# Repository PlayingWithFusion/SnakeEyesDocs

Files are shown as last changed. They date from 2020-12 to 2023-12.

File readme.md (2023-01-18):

# [SnakeEyes Raspberry Pi Hat](https://www.playingwithfusion.com/productview.php?pdid=133&catid=1014)

## What Is It?

SnakeEyes is a circuit board which conforms to the Raspberry Pi hat physical specifications, and provides the following functionality:

 * 12V Passive POE extraction (for supported Pi models)
 * High-power, software-dimmable LED target illumination
   * Two versions available: [**traditional green**](https://www.playingwithfusion.com/productview.php?catid=1014&pdid=133) and [**infrared**](https://www.playingwithfusion.com/productview.php?catid=1014&pdid=134).
 * Regulated power supply for LED's and Raspberry Pi main board
 * Connections for cooling fan

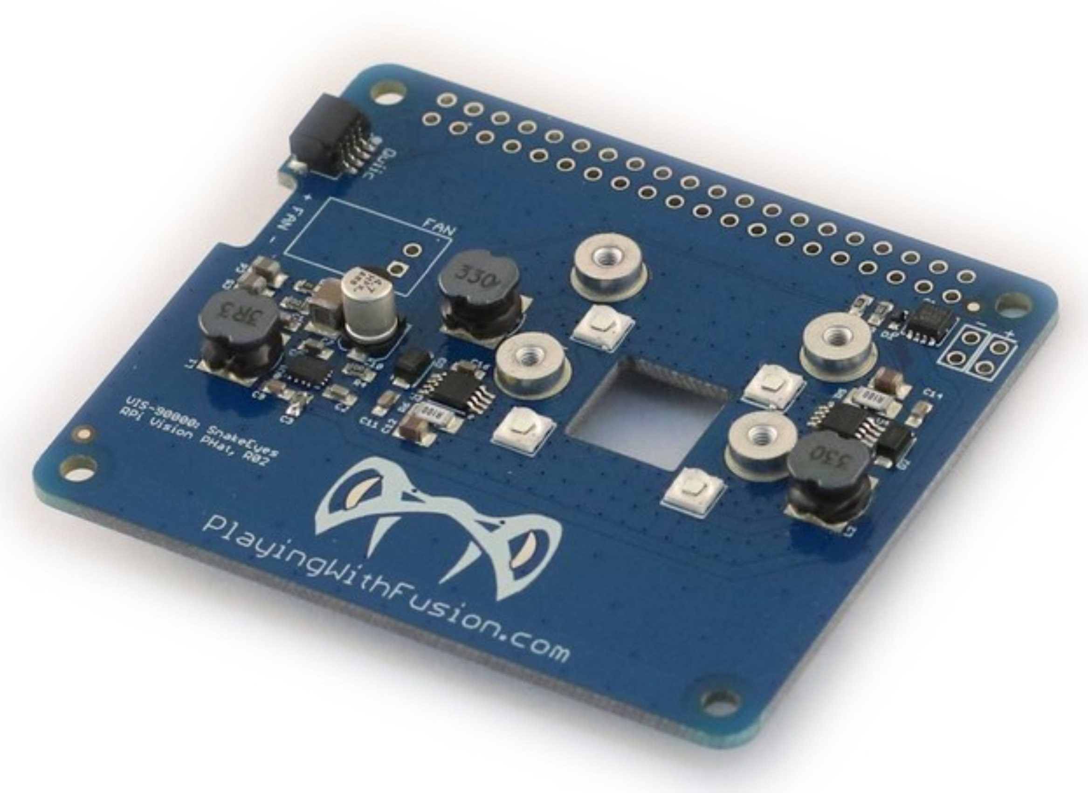
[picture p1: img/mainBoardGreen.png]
SnakeEyes main board photo


## What Is It Not?

SnakeEyes is designed to be one core component in a vision processing solution - it is not a plug-and-play vision processing solution by itself. The goal is to give teams flexibility to build and customize a system as they desire, while robustly taking care of "less-critical" electrical considerations.

SnakeEyes will require some assembly and fabrication, as well as some work to load and run software. 

## How to Use This Guide

This is a guide to help you get set up using the SnakeEyes vision processing hat. 

The platform is designed for experimentation! The goal is help DIY folks with a portion of their development process. 

This guide seeks to further help by providing a few known-good paths to success.

# Getting Started

 1. [Video Introduction to the Product](https://www.youtube.com/watch?v=mmTHJN22qKk&feature=youtu.be)
 2. [Required Additional Hardware](hardware.md)
 3. [Sample 3D Printed Case Designs](case/)
 4. [Sample Software Options](sampleSoftware.md)

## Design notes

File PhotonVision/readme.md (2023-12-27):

# PhotonVision and SnakeEyes

[PhotonVision](https://photonvision.org) is one option for vision processing software which is compatible with SnakeEyes.

# Getting Started

Download the latest [preconfigured SnakeEyes Image](https://github.com/PlayingWithFusion/SnakeEyesDocs/releases).

Flash it onto an SD card [using the same process as recommended by PhotonVision](https://docs.photonvision.org/en/latest/docs/getting-started/installation/sw_install/raspberry-pi.html)

The reset of the [PhotonVision docs](https://docs.photonvision.org/en/latest/index.html) should apply as normal.

# Technical Details

The only modification to PhotonVision required to use SnakeEyes is to ensure the [`hardwareConfig.json`](hardwareConfig.json) file is updated to enable dimmable LED support on pin 13.

In 2024, PhotonVision migrated to using an SQLite database to store settings. Its contents is functionally the same as the `hardwareConfig.json` file. The SnakeEyes preconfigured image includes a small database with the LED's configured, but no cameras or pipelines configured. On PhotonVision's first launch, it will fill out the rest of the details for your model of Pi and camera config.

# Legacy Update Process

While still functional for the 2024 season, this method may be removed in the future. 

First, download the hardware config file, `hardwareConfig.json`. [Click this link](https://raw.githubusercontent.com/PlayingWithFusion/SnakeEyesDocs/master/PhotonVision/hardwareConfig.json), then save the file.

[Follow the instructions for installing PhotonVision.](https://docs.photonvision.org/en/latest/docs/getting-started/installation/coprocessor-image.html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)

Go to `http://photonvision.local:5800/settings.html`, select Import Settings, and upload `hardwareConfig.json`.

Successful configuration should allow you to see and control the LED brightness from the PhotonVision Settings page:

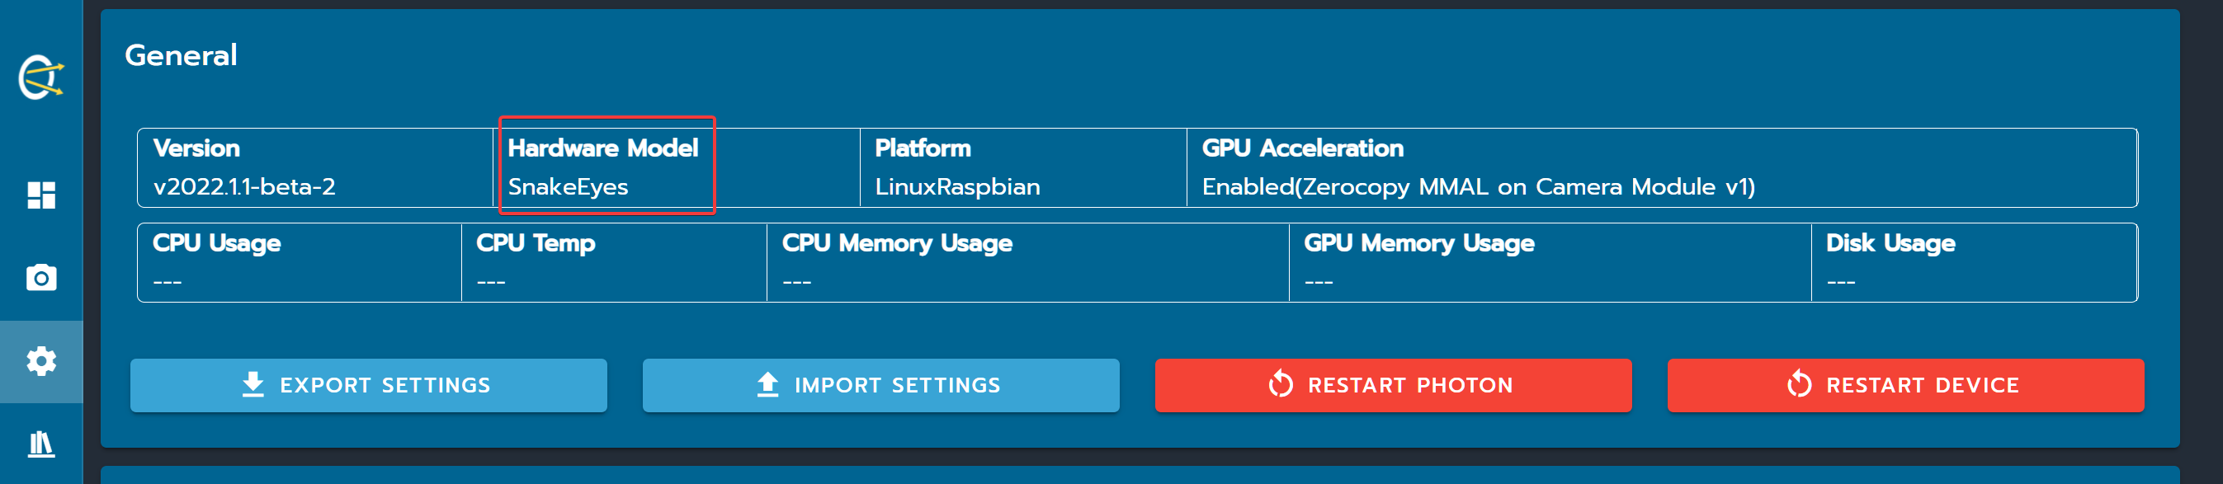
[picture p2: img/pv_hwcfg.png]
hardware config


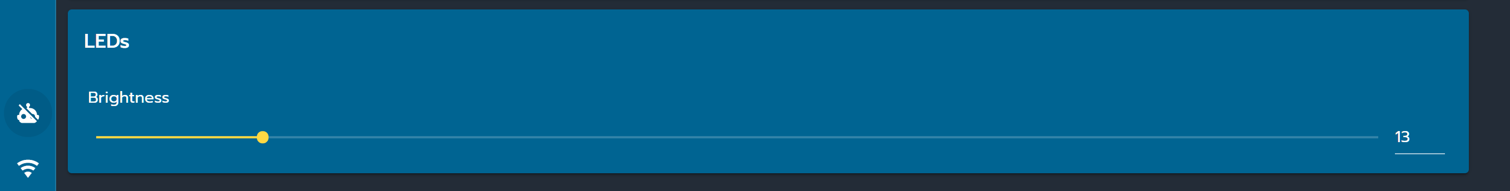
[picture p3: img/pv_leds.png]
LED slider


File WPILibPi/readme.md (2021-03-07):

# WPILibPi and SnakeEyes

This sample code runs on the WPIlib Raspberry Pi Image, and performs basic image processing on an IR camera, as well as interfaces with an LED & power supply hat from Playing With Fusion.

The sample code assumes the Raspberry Pi NOIR camera is in use, and no other cameras are attached to the system.

# Getting Started

This procedure was last tested with the v2021.2.1 release of WPILib Pi.

## Code

Download a copy of the sample [`snakeEyesVision.py`](https://raw.githubusercontent.com/PlayingWithFusion/SnakeEyesDocs/master/WPILibPi/snakeEyesVision.py) script. Modify the `TEAM_NUMBER` variable to match your team, along with other configuration as needed.

## Upload

[Download and flash the latest version of the FRCVision Raspberry Pi Image per their instructions.](https://docs.wpilib.org/en/stable/docs/software/vision-processing/raspberry-pi/installing-the-image-to-your-microsd-card.html)

Power the system up, visit the web interface, and ensure you can see the Raspberry Pi camera as the only camera on the system, and can view its stream.

[Reference the Vision Workflows documentation](https://docs.wpilib.org/en/stable/docs/software/vision-processing/raspberry-pi/the-raspberry-pi-frc-console.html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) to upload your modified `snakeEyesVision.py`.

> :bug: To debug, you can change to the `Vision Status` tab, and ensure you have messages indicating the vision processing logic has started.

> :bug: Note that the python example uses the `RPi.GPIO` libraries for controlling the pins as a simple proof of concept. However, since it only supports software PWM, you may see **occasional flickering** in the output intensity at partial values. In the future, we're looking to use `pigpio` as an alternative, but that requires more complex integration.

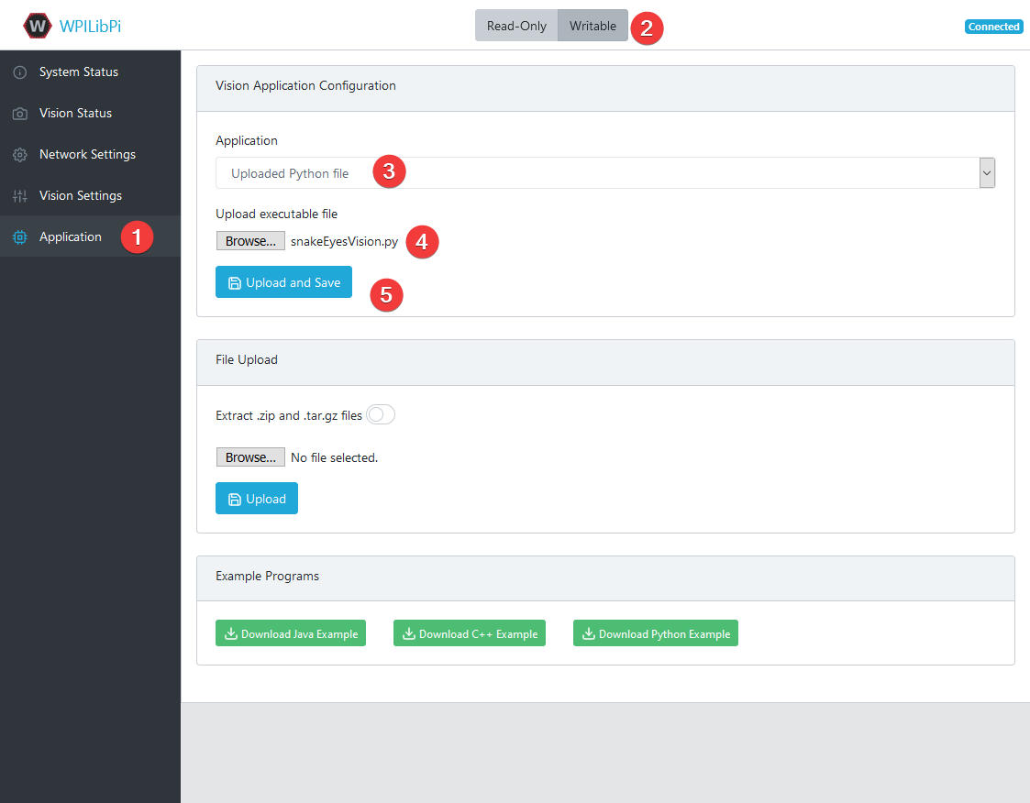
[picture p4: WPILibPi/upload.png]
upload sequence


Once the code is running, visit [`http://wpilibpi.local:5805/stream.html`](http://wpilibpi.local:5805/stream.html) in a web browser to see a stream of the processed camera data and some stats.

You can read the target information from Network Tables values `targetX`, `targetY`, and `targetVisible`.

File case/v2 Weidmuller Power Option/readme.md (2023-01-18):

# v2 Case with Weidmuller Power Access

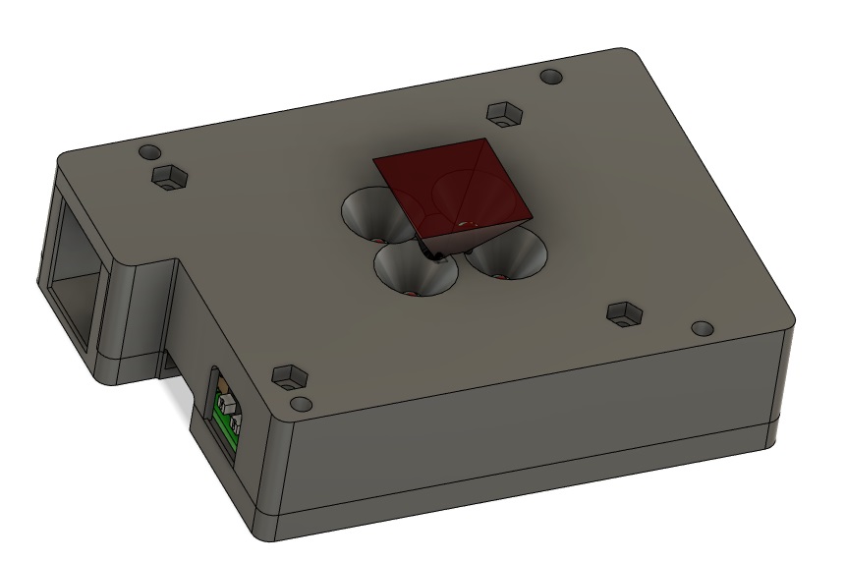
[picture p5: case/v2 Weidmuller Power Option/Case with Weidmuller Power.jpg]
v2 caseW eidmuller


This case improves the v1 design with fewer clearance issues, fewer small parts to manage, and increased sd card access. It also includes access port for the external Weidmuller power ports.

You will need all the same metric bolt hardware as the v1 case, and need to print one of each .stl.

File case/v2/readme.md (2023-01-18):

# v2 Case

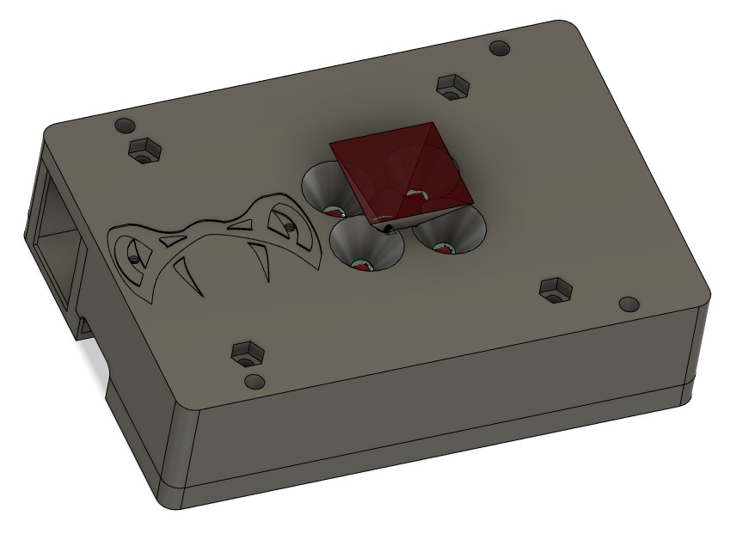
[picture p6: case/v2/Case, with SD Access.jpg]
v2 case


This case improves the v1 design with fewer clearance issues, fewer small parts to manage, and increased sd card access.

You will need all the same metric bolt hardware as the v1 case, and need to print one of each .stl.

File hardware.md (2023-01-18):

# Hardware

This page describes the minimum additional hardware required to enable all functionality of the SnakeEyes board.

> :warning: If you are using the [Sample Case Design](case/v1/sampleCase.md), be sure to read that page too - it has additional components and requirements above and beyond these minimum requirements.

## BOM

| No. | Description | Quantity | Example Source
| --- | --- | --- | --- |
| 1 | SnakeEyes Pi Hat | 1 | [Green](https://www.playingwithfusion.com/productview.php?catid=1014&pdid=133) or [IR](https://www.playingwithfusion.com/productview.php?pdid=134)
| 2 | Compatible Raspberry Pi | 1 | See below
| 3 | 20x2 0.1" pitch header | 1 | Included, or [Kit from Amazon.com](https://www.amazon.com/gp/product/B076H25ZB8)
| 4 | 2x2 0.1" pitch header | 1 | Included, or [Kit from Amazon.com](https://www.amazon.com/gp/product/B076H25ZB8)
| 5 | Pi V2 or V1.3 Camera | 1 | [Green](https://www.raspberrypi.org/products/camera-module-v2/?resellerType=home) or [IR](https://www.raspberrypi.org/products/pi-noir-camera-v2/?resellerType=home) 
| 6 | M2x10mm screws | 4 | [Set from Amazon.com](https://www.amazon.com/uxcell-M2x10mm-Phillips-Stainless-Fasteners/dp/B07LGWJ9LJ/)
| 7 | Short Camera Cable | 1 | [Set from Amazon.com](https://www.amazon.com/Pastall-Raspberry-15cm%C3%972pcs-30cm%C3%972pcs-50cm%C3%972pcs/dp/B089LM5D1T)
| 8 | 12v cooling fan | 1 | [Set from Amazon.com](https://www.amazon.com/gp/product/B01406OSNE)
| 9 | Case | 1 | [Sample Case Design](case/v1/sampleCase.md), one of the v2 designs, or create your own.

## Component Details

### Raspberry Pi

SnakeEyes is designed to fit the "hat" form-factor of the [Raspberry Pi Single Board computer](https://www.raspberrypi.org/products/). Specifically, the following variants have been tested:

 * [4 Model B](https://www.raspberrypi.org/products/raspberry-pi-4-model-b/?resellerType=home)
 * [3 Model B+](https://www.raspberrypi.org/products/raspberry-pi-3-model-b-plus/?resellerType=home)
 * [3 Model B](https://www.raspberrypi.org/products/raspberry-pi-3-model-b/?resellerType=home)

Others will likely function, but have not been fully tested. Earlier models had limited processing power, so your algorithm's performance may not be as good as with recent models.

### Headers & Soldering

SnakeEyes does not come assembled with the headers required to interface with a Raspberry Pi. 

Carefully solder all headers onto the SnakeEyes board. Use jigs as needed to ensure the headers are straight and flush with the PCB, as this alignment contributes to the overall camera alignment in the unit.

> :warning: Use particular caution soldering near the small 4-pin header - it is easy to damage nearby surface-mount components.

The 2x2 pin header is used for Power over Ethernet.

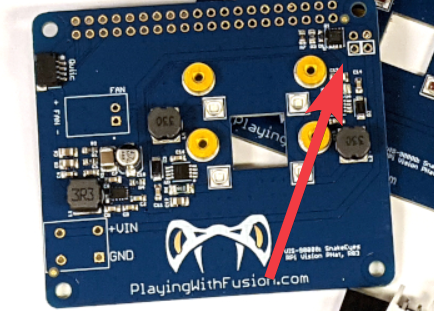
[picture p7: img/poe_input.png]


 If you are using a Raspberry Pi model which does not support power over ethernet (like the 3 Model B), or do not wish to use Power over Ethernet, you may alternatively use the alt power input pins

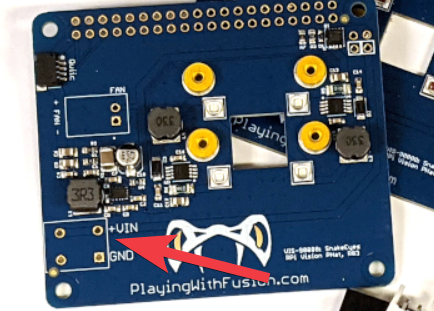
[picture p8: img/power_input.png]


Additional headers are provided for the fan and alt power input. Be sure to confirm the case design being used has clearance for each header before soldering.

### Camera 

In addition, you will need to purchase a Camera. 

#### Requirements

SnakeEyes is designed to accept any "Camera Module V2" format Raspberry Pi Camera. This also includes most of the v1.3 Raspberry Pi Cameras as well. 

> :warning: **Use caution while routing the ribbon cable!** Many are sensitive to folds or creases. You will need at least one 90-degree bend to get proper orientation of the camera relative to the case

It is recommended to use a 15cm ribbon cable.[If your camera does not come with one, this kit will provide a variety of options for spares and experimentation](https://www.amazon.com/Pastall-Raspberry-15cm%C3%972pcs-30cm%C3%972pcs-50cm%C3%972pcs/dp/B089LM5D1T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).

Pi V2 Cameras are designed to be mounted with standard M2 bolts.

> :warning: Aside from providing a mounting location and target illumination, **SnakeEyes does not directly interact with the camera.** Playing With Fusion can offer very limited support on camera choice or functionality.

#### Traditional / Green LED

For most vision processing tasks (including using green LED's to identify retroreflective tape around targets), any Pi V2 camera should function fine. It is recommended to use the [official Pi camera module](https://www.raspberrypi.org/products/camera-module-v2/?resellerType=home), though many cheaper models on Amazon have been tested functional.

#### IR / Red LED

If you are using the Red IR version of SnakeEyes, it is highly recommended to use a camera which does not contain an IR filter. [The official Raspberry Pi NOIR Camera](https://www.raspberrypi.org/products/pi-noir-camera-v2/?resellerType=home) is the current recommendation.

> :warning: While using a camera with an IR filter may function, it will severely reduce the usefulness of the IR-spectrum illumination the SnakeEyes provides.

### Fan

The SnakeEyes LEDs and the Raspberry Pi itself produce a decent amount of heat while under load. It is highly recommended to use a fan to cool the system while in operation.

Any small 12v fan will work. Ensure the +/- polarity of the connector of your fan aligns with the polarity labels on SnakeEyes - there is no standard for how the connectors get wired.

### Case

SnakeEyes must be contained within a case for proper functionality. The case must serve a few purposes:

 * Shield the camera from the LED's with opaque material
   * Without this, spill light from the LED's will wash out the image, and made target identification very hard.
* Protect the electronics 

## LED Control

LED brightness is controlled by the Raspberry Pi pin GPIO 13. Configure the pin as an output, sending a 5kHz-8kHz square wave. Vary the duty cycle from 0% to 100% to change LED brightness.

Control is active-high - the pin must be pulled high in order to turn on the LED's.

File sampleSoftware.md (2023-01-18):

## Software

Almost any Raspberry Pi based vision processing solution could be made to function with SnakeEyes. There are currently two tested paths to success:

### PhotonVision

[PhotonVision](https://photonvision.org/) is an open-source GUI-based vision system. 

It is the preferred approach for software to interact with SnakeEyes.

[Click here for documentation on using SnakeEyes with PhotonVision](PhotonVision/readme.md). 

### WPILibPi

[WPILib provides a raspberry Pi image with many common utilities pre-installed](https://docs.photonvision.org/en/latest/docs/getting-started/installation/sw_install/snakeyes.html).

[Click here for documentation on using SnakeEyes with the WPILibPi Image](WPILibPi/readme.md)

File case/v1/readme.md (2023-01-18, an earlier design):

# v1 Case

[This case design](https://cad.onshape.com/documents/f103c7ef3fd26794c458b982/w/31e132f18a5a8b15dab352ca/e/fb93b9d1fb39f2f70ae6d80d) is provided as a reference, 3d-printable design for using the SnakeEyes with a Raspberry Pi 3b, 3b+, and 4b. 
[A video with assembly instructions is provided](https://youtu.be/iXhFbSNitfY).

## BOM

| No. | Description | Quantity | Example Source
| --- | --- | --- | --- |
| 1 | Assembled SnakeEyes Electronics | | See [Hardware BOM](hardware.md)
| 2 | 3d Printed Parts | | See Below
| 3 | M2.5x25 Bolt & Nut | 4 | Included, or [Kit from Amazon.com](https://www.amazon.com/gp/product/B082XPZV1V/)
| 4 | 25x25x10mm Cooling Fan | 1 | [Set from Amazon.com](https://www.amazon.com/gp/product/B01406OSNE). 

## Component Details

### Headers

This case is designed assuming headers with a 8.35mm plastic body height to provide proper separation between the SnakeEyes board and the Raspberry Pi case. Some "Raspberry-Pi" labeled headers have additional plastic layers which make them too tall for the case.

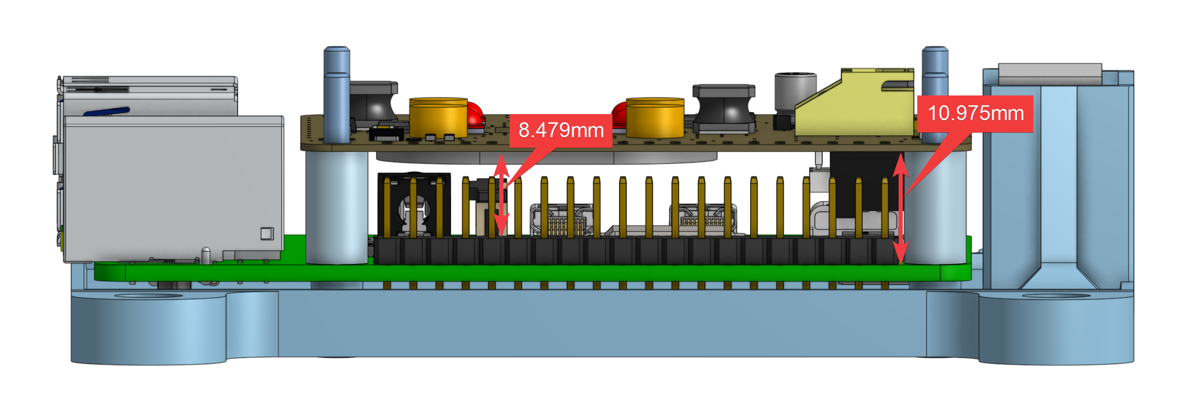
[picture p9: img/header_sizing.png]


Confirm whether your case has clearance to mount the external power connector on the top of the board. Soldering wires directly to the board or on the underside are alternatives if not.

### 3d-Printed Parts

After downloading the .stl files, you will need to export and print the following:

 * 1x `Bottom`
 * 1x `Top`
 * 4x `Main Board Spacer`
 * 1x `Camera Board Spacer Plate`

If the LED's will be driven at full brightness, PETG or ABS is recommended to prevent warping from the heat. 

> :warning: Be sure to choose a filament color which is opaque to the wavelengths of light being used. Black is a good choice. Red is a bad one for the IR lED's

## Assembly

### Electronics Prep

Place the SnakeEyes board face-down on your work surface.

Place the `Camera Board Spacer Plate` over the camera mounting holes. 

Position the camera on top of the spacer plate and secure with M2 screws. 

> :bulb: Tighten each bolt to similar tightness to ensure the camera face is not skewed relative to the SnakeEyes main board.

> :warning: Be careful not to over-tighten the bolts and damage the camera printed circuit board.

Connect the camera's ribbon cable to both the camera and the raspberry pi board.

Lightly route the ribbon cable with the required 90deg bend, and two 180deg bends to get it aligned properly to the Raspberry Pi's connector. This is prep work to make it easier to route the cable when assembling the full case.

### Main Case Assembly

Place four M2.5x25 bolts upward through the `Bottom` half of the case.

Slide the Raspberry Pi onto the four bolts.

Place the 4 `Main Board Spacer`s onto the bolts.

Slide the SnakeEyes + Camera assembly onto the bolts.

Press the headers downward to mate the SnakeEyes board to the Pi

> :warning: Carefully push and prod the camera ribbon cable to get it to fit between the boards with minimal pinching.

Place the fan into the holder and connect it to the board-mount jack. Carefully wrap up or route wires away from the camera/LED cluster and the bolts.

Place the `Top` portion of the case over the whole assembly. Push down lightly to compress the spacer/PCB stack. Watch out for pinched wires as you do this - re-route as needed.

Carefully, slide one corner off the edge of the work surface, holding the M2.5 bolt in place with your finger. Place a M2.5 nut into the `Top` portion of the case and twist the bolt to engage it. Repeat for all bolts.

Tighten down all four bolts with an allen wrench. Use a moderate amount of torque: Not enough to strip out your plastic material, but enough to keep the whole structure rigid.

Mount the device to the location on your robot. The outer holes are designed to take 10-24 bolts.

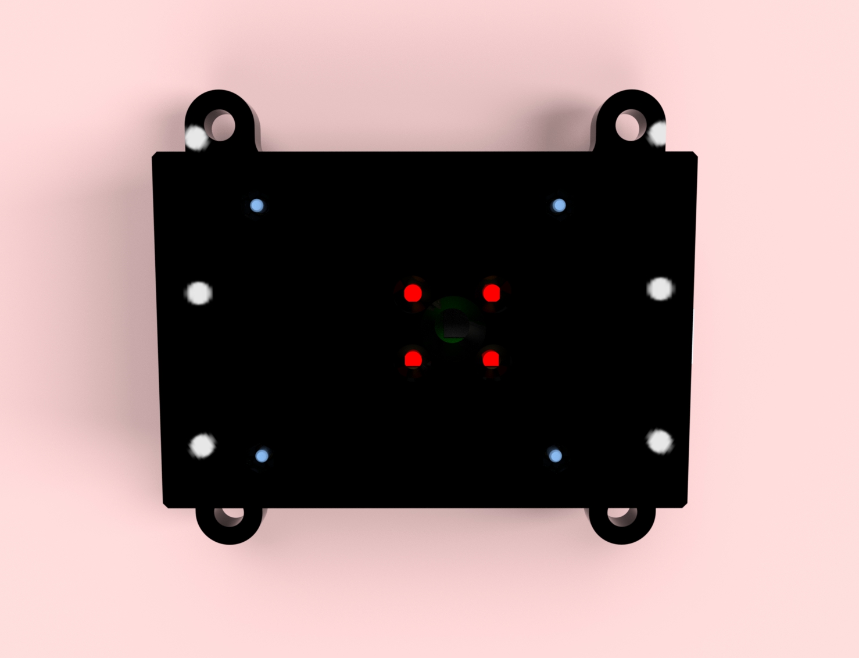
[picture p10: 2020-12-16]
img/render_4.jpg

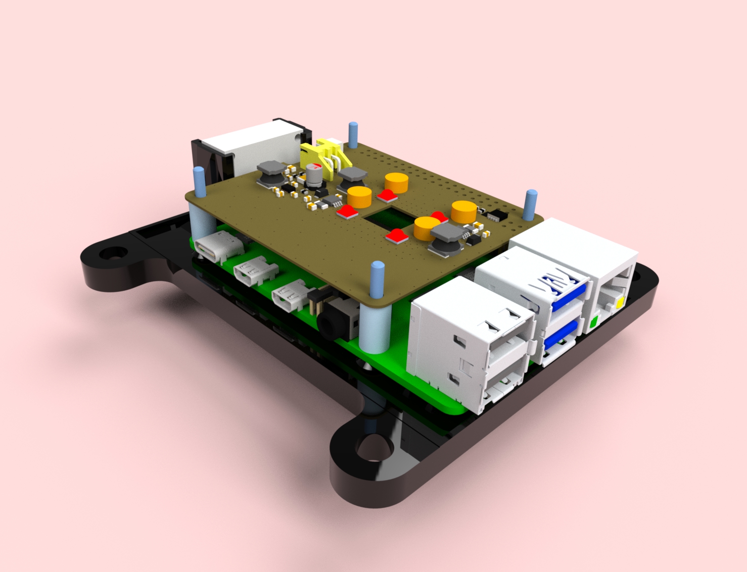
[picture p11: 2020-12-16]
img/render_9.jpg

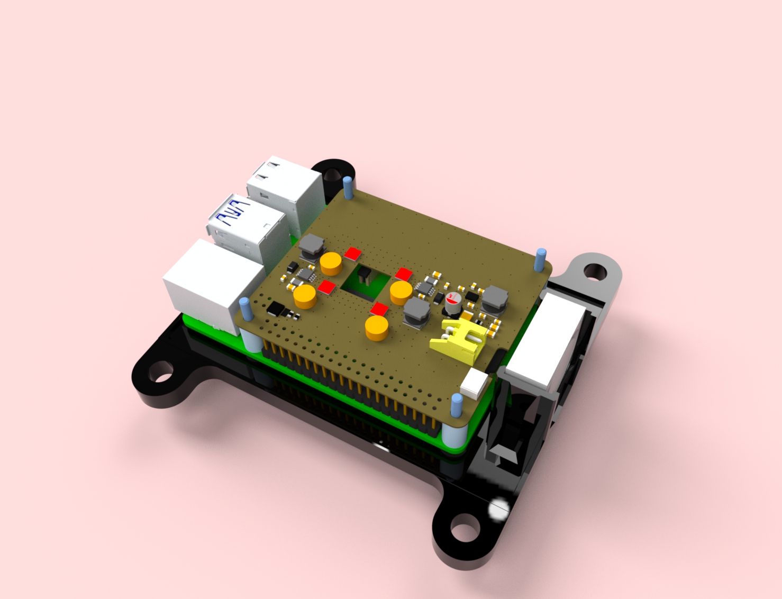
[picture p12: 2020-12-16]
img/render_6.jpg

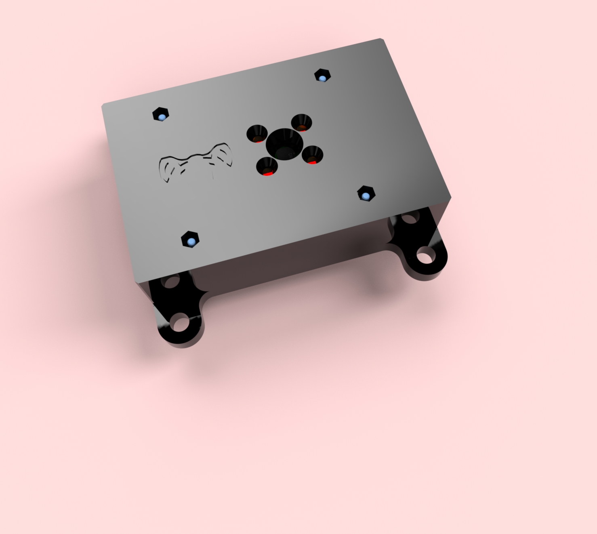
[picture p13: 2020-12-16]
img/render_10.jpg

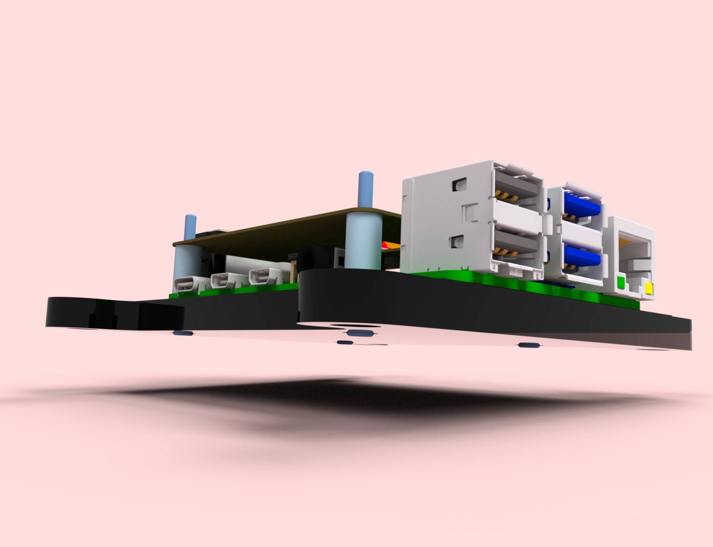
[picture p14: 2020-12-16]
img/render_7.jpg

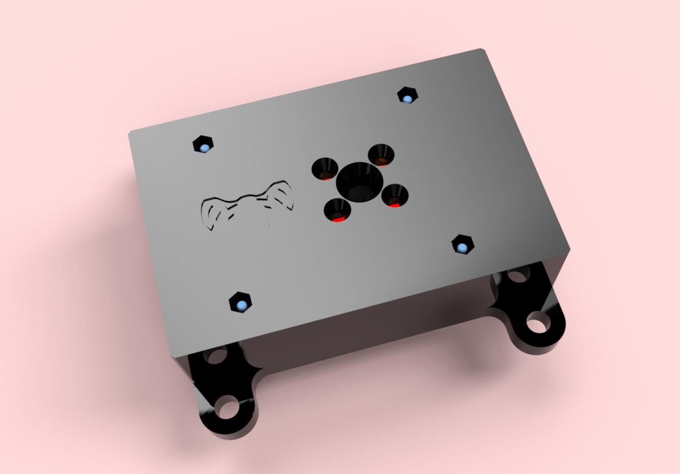
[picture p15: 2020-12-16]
img/render_11.jpg

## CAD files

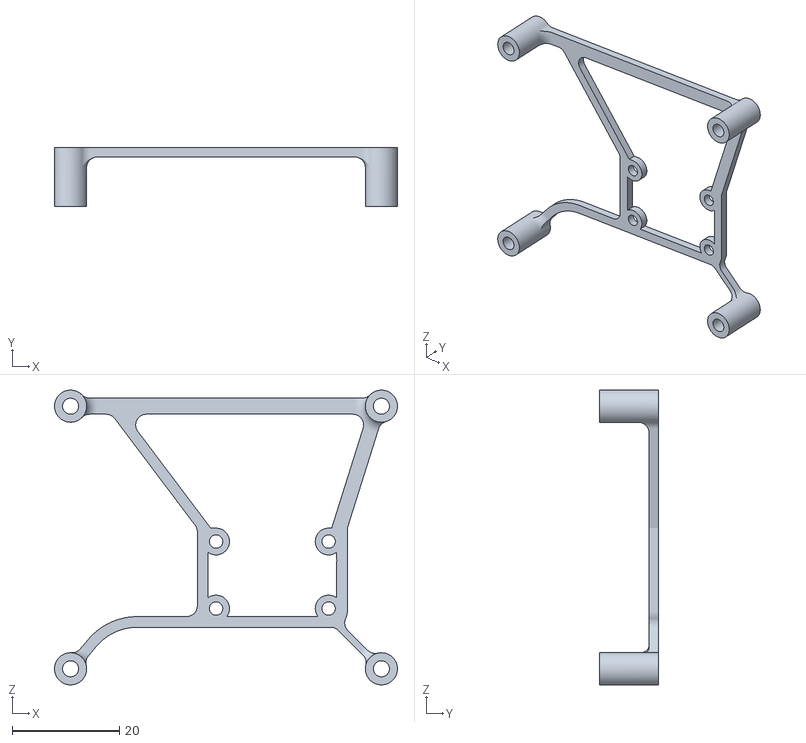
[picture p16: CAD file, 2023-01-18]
case/v2 Weidmuller Power Option/SpacerAssy.stl
64.0 x 11.0 x 55.0

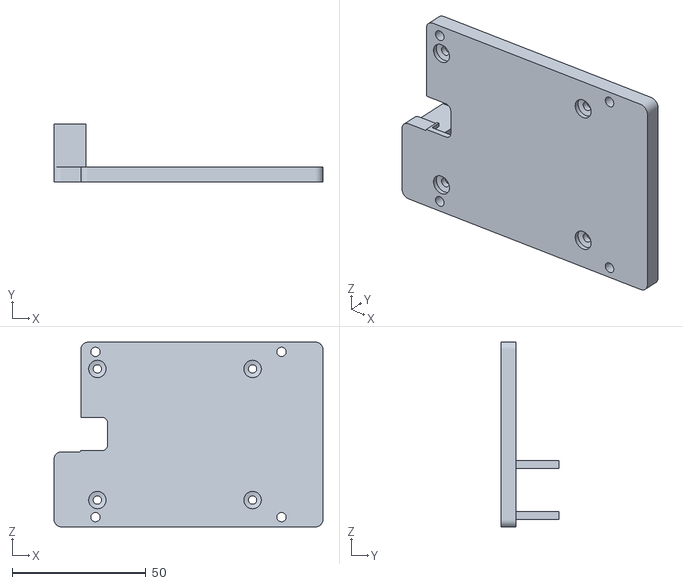
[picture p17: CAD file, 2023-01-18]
case/v2 Weidmuller Power Option/Case Bottom.stl
100.5 x 21.5 x 69.0

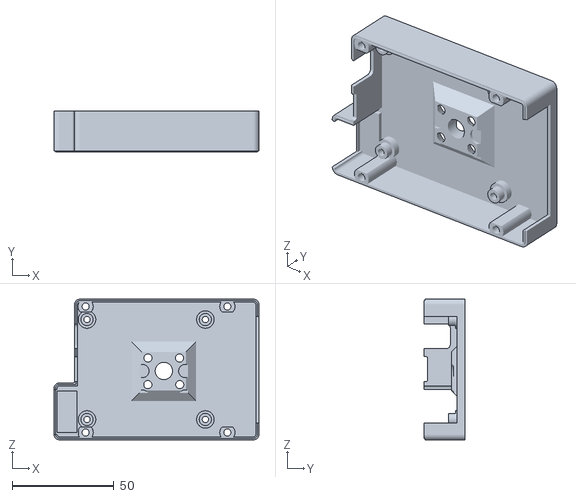
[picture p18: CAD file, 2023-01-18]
case/v2 Weidmuller Power Option/Case Top.stl
100.5 x 20.3 x 69.0

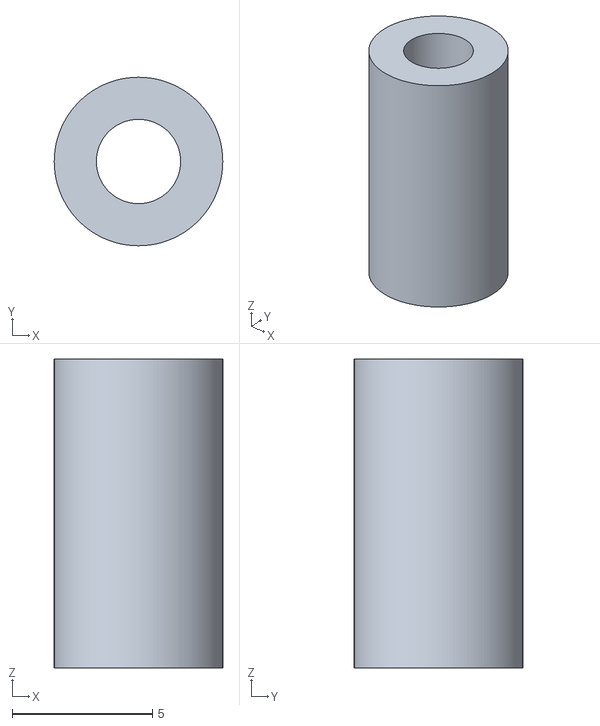
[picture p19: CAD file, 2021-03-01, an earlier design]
case/v1/Parts - Main Board Spacer.stl
6.00 x 6.00 x 11.0

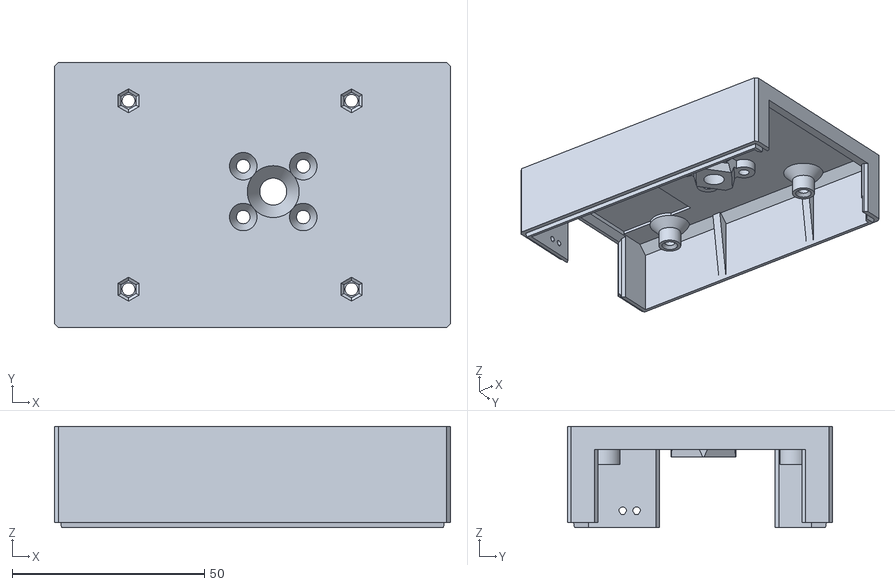
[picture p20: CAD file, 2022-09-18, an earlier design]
case/v1/Parts - Top.stl
103.0 x 69.0 x 26.4

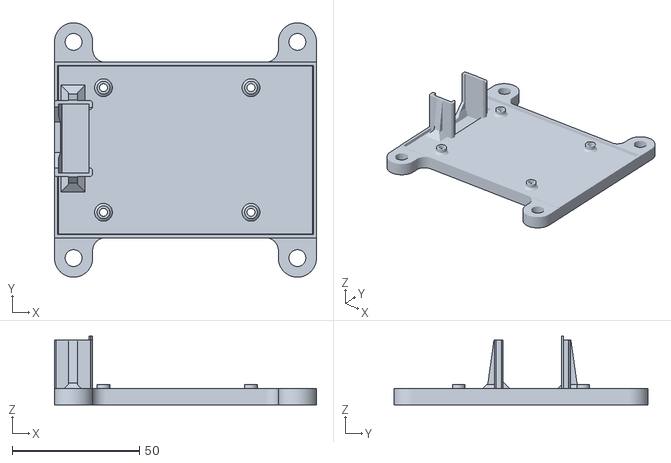
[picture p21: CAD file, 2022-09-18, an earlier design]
case/v1/Parts - Bottom.stl
103.0 x 100.0 x 27.0

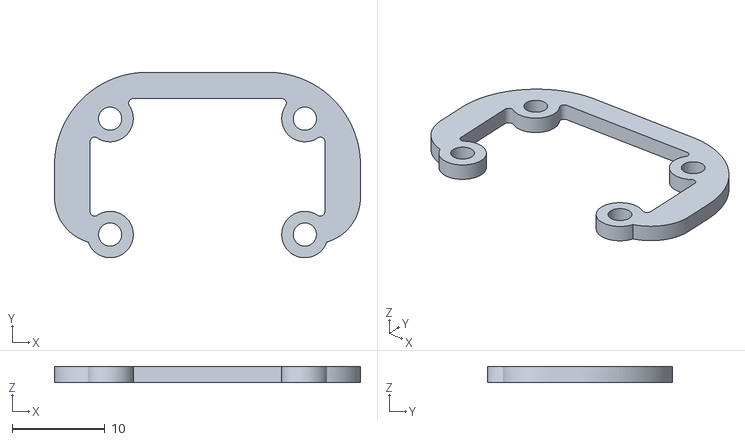
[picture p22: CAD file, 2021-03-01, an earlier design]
case/v1/Parts - Camera Board Spacer Plate.stl
33.0 x 20.0 x 1.75

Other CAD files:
case/v2/Case Bottom.stl

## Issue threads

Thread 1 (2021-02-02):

Weidmuller on top interferes with sample case

ngreen-gt, 2021-02-02:
The sample case only fits if you solder the  Weidmuller connector to the bottom of the board, otherwise the case hits the connector.    In the video, it says either side is okay (06:30).  A note in sampleCase.md on this would be helpful.

gerth2, 2021-12-29:
#4 should add comments about it.

I was poking around at how to accommodate it in the case (the onshape model has an older board that didn't model it). Adding a cutout might be feasilbe?

gerth2, 2023-01-18:
Two new case designs added to reduce these issues.

Closed 2023-01-18.

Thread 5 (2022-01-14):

Case source files?

allengregoryiv, 2022-01-14:
Is it possible to get a STEP or source CAD files for the snake eyes case? Modifying the STL files is not the easiest/cleanest way to go.

fusionstein, 2022-01-15:
Hi Allen, the full CAD is available in Onshape here: https://cad.onshape.com/documents/f103c7ef3fd26794c458b982/w/31e132f18a5a8b15dab352ca/e/fb93b9d1fb39f2f70ae6d80d

Let me know if you have any questions, and have a great weekend! If all goes well, we'll post a video or two showing our start to the vision solution.

-Justin

Closed 2023-01-18.

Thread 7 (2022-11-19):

Included bolts not long enough for latest version of the case

viggy96, 2022-11-19:
I recently purchased a SnakeEyes hat, and I printed the latest version of the case, however, I found that the longer 25mm bolts aren't long enough to reach to the top piece and thread onto the nuts. I had to go back to the 2022 version.

I spent ages trying to figure out what I was doing wrong when assembling the unit.

gerth2, 2023-01-18:
new case designs have been added to address the issues.

Closed 2023-01-18.

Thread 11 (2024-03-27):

Suporting PhotonVision 2024.3.1?

swalberg, 2024-03-27:
I downloaded the Release_18 image and flashed it to a Raspberry Pi 4. It booted and worked fine. I then went through the offline update procedure to upgrade to the latest Linuxarm64 version of PhotonVision. It boots, but can't see the camera (only shows "placeholder camera"), nor do any of the stats show:

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

I do see some shared library problems in the logs:

```
Mar 27 10:24:08 photonvision java[1688]: [2024-03-27 10:24:08] [Camera - MrCalJNILoader] [ERROR] Couldn't load shared object mrcal_jni: /tmp/libmrcal_jni.so: libsuitesparseconfig.so.5: cannot open shared object file: No such file or directory
Mar 27 10:24:08 photonvision java[1688]: [2024-03-27 10:24:08] [Camera - LibCameraJNILoader] [ERROR] Couldn't load shared object photonlibcamera: /tmp/libphotonlibcamera.so: libcamera.so.0.1: cannot open shared object file: No such file or directory
```

Other interesting logs:

```
Mar 27 10:24:14 photonvision java[1688]:         at java.base/java.lang.Thread.run(Thread.java:829)
Mar 27 10:24:14 photonvision java[1688]:         at org.photonvision.common.dataflow.DataChangeService.dispatchFromQueue(DataChangeService.java:65)
Mar 27 10:24:14 photonvision java[1688]:         at org.photonvision.server.UIInboundSubscriber.onDataChangeEvent(UIInboundSubscriber.java:46)
Mar 27 10:24:14 photonvision java[1688]:         at org.photonvision.common.configuration.PhotonConfiguration.toHashMap(PhotonConfiguration.java:138)
Mar 27 10:24:14 photonvision java[1688]:         at org.photonvision.raspi.LibCameraJNILoader.isSupported(LibCameraJNILoader.java:77)
Mar 27 10:24:14 photonvision java[1688]:         at org.photonvision.raspi.LibCameraJNI.isSupported(LibCameraJNI.java:65)
Mar 27 10:24:14 photonvision java[1688]:         at org.photonvision.raspi.LibCameraJNI.isLibraryWorking(Native Method)
Mar 27 10:24:14 photonvision java[1688]: Exception in thread "DataChangeEventDispatchThread" java.lang.UnsatisfiedLinkError: 'boolean org.photonvision.raspi.LibCameraJNI.isLibraryWorking()'
```

swalberg, 2024-03-27:
```
root@photonvision:/var/log# find / -name libcamera.so\*
/usr/lib/aarch64-linux-gnu/libcamera.so.0.0.3
root@photonvision:/var/log# find / -name libsuitesparseconfig.so\*
root@photonvision:/var/log#```

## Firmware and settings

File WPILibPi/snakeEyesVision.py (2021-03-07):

#!/usr/bin/env python3
#----------------------------------------------------------------------------
# Copyright (c) 2020 Playing With Fusion. See license.txt for more info.
#
# This is a sample python program for configuring and using the NoIR Camera
# with the WPILibPi Raspberry Pi Image and Playing With Fusion's infrared
# LED hat. 
#
# Results of the processing are visible at http://wpilibpi.local:5805/stream.html
# and in Network Tables.
#----------------------------------------------------------------------------

# General Python Libraries Used
import time
import sys, os, math, collections
import threading
from http.server import BaseHTTPRequestHandler, HTTPServer
from socketserver import ThreadingMixIn

# Computer Vision & Processing Libraries
import numpy as np
import cv2

# FRC Network Tables 
from networktables import *

# GPIO Pin Manipulation
# Note this library only does software PWM, 
# so you may see flickering. So far it hasn't impacted
# vision performance.
# The alternate is to install and use the pigpio or RPIO libraries
# for python, or some alternate mechanism which leverages
# the Pi's hardware PWM to get more stable dimming.
import RPi.GPIO as GPIO




######################################################################
## Configuration Constants - Adjust these as needed
######################################################################
# Global Configuration

# Team Setup
TEAM_NUMBER    = 1736

# Camera Setup
CAPTURE_WIDTH  = 320
CAPTURE_HEIGHT = 240
CAPTURE_FPS    = 90

# Vision Processing Pipeline Configuration
MIN_PIXEL_BRIGHTNESS = 100
MAX_PIXEL_BRIGHTNESS = 255
MIN_CONTOUR_WIDTH_PX = 15
MIN_CONTOUR_AREA_PX  = 20

# Control how bright the LED's are set to
# 0.0 = Off, 1.0 = full on.
LED_BRIGHTNESS = 0.25

# Debug Flags
imgProcPrintDebug = False
webServerPrintDebug = False
drawPixelMask = False
drawContours = True
drawStatsOverlay = True


######################################################################
## Sample Vision Processing Pipeline
######################################################################
class SimpleVisionPipeline():

    def __init__(self):
        ##IR Light & Camera Identification Thresholds (HSV)
        self.lowerBrightness=np.array([0,0,MIN_PIXEL_BRIGHTNESS])
        self.upperBrightness=np.array([255,255,MAX_PIXEL_BRIGHTNESS])
        self.fps = 0


    ###########################################
    # Main Processing Pipeline
    ###########################################
    def process(self, inFrame):

        # Save copy of the input frame. Default to output the same image.
        self.inimg = inFrame
        self.maskoutput = inFrame

        # Find pixels which could be part of a target
        self.pixelFilter()

        # Find contours around candidate pixels
        _, contours, _ = cv2.findContours(self.mask, mode=cv2.RETR_LIST, method=cv2.CHAIN_APPROX_SIMPLE)

        # Filter contour list to only reasonably-sized ones.
        filteredContours = self.filterContours(contours, MIN_CONTOUR_AREA_PX, MIN_CONTOUR_WIDTH_PX, math.inf)
        
        # Identify target location from the given contour list
        self.detectTarget(filteredContours)

        # Update Network Tables with processing results
        self.updateNTOutputs()

        # Draw debug info on the video output
        self.debugDraw()

        if imgProcPrintDebug:
            self.outputStr = "{},{},{}\n".format(self.targetVisible, self.xval, self.yval)
            print(self.outputStr)

        # Return a modified image for streaming to the website
        return self.maskoutput


    ###########################################
    # Pipeline Step Implementation
    ###########################################
    def pixelFilter(self):
        #Sets image to hsv colors
        hsv = cv2.cvtColor(self.inimg, cv2.COLOR_RGB2HSV)

        #Creates mask based on hsv range
        self.mask = cv2.inRange(hsv, self.lowerBrightness, self.upperBrightness)

    def filterContours(self, input_contours, min_area, min_width, max_width):
        output = []
        for contour in input_contours:
            # Reasonably contours will be in a certain range of widths.
            x,y,w,h = cv2.boundingRect(contour)
            if (w < min_width or w>max_width):
                continue

            # Reasonable contours will have a minimum amount of area
            area = cv2.contourArea(contour)
            if (area < min_area):
                continue
            output.append(contour)

        return output
        

    def detectTarget(self, contourinput):

        self.targetVisible = False
        self.xval = 0
        self.yval = 0

        if contourinput:
            #Simple assumption # 1: Biggest contour must correspond to the target.
            self.contoursSorted = sorted(contourinput, key=cv2.contourArea, reverse=True)
            self.targetContour = self.contoursSorted[0]
            self.targetVisible = True

            #Simple Assumption # 2: The target is "located" at the center of the contour.
            M = cv2.moments(self.targetContour)
            self.xval = M["m10"] / M["m00"]
            self.yval = M["m01"] / M["m00"]


    def debugDraw(self):

        if drawPixelMask:
            self.maskoutput = cv2.cvtColor(self.mask, cv2.COLOR_GRAY2BGR)

        if drawContours:
            if(self.targetVisible):
                cv2.drawContours(self.maskoutput,[self.targetContour], -1, (0,255,0), 2)
                cv2.drawContours(self.maskoutput,self.contoursSorted[1:], -1, (0,125,125), 2)
                cv2.circle(self.maskoutput,(int(self.xval),int(self.yval)),3,(20,20,20), -1)
                cv2.circle(self.maskoutput,(int(self.xval),int(self.yval)),1,(0,255,255), -1)

        if drawStatsOverlay:
            printXStr = "X:" + "{:7.2f}".format(self.xval) if self.targetVisible else " "*7
            printYStr = "Y:" + "{:7.2f}".format(self.yval) if self.targetVisible else " "*7
            statsStr = "FPS:{:6.2f}".format(self.fps)
            cv2.rectangle(self.maskoutput, (0,0), (CAPTURE_WIDTH,15),(0,0,0),-1)
            cv2.putText(self.maskoutput, statsStr, (3, 12), fontFace=cv2.FONT_HERSHEY_PLAIN, fontScale=1, color=(255, 255, 255))  
            cv2.putText(self.maskoutput, printXStr, (100, 12), fontFace=cv2.FONT_HERSHEY_PLAIN, fontScale=1, color=(255, 255, 255))  
            cv2.putText(self.maskoutput, printYStr, (200, 12), fontFace=cv2.FONT_HERSHEY_PLAIN, fontScale=1, color=(255, 255, 255))  


    def updateNTOutputs(self):
        ntTable.putNumber("targetX", self.xval)
        ntTable.putNumber("targetY", self.yval)
        ntTable.putNumber("targetVisible", self.targetVisible)

    def setDispFPS(self, fps_in):
        self.fps = fps_in

######################################################################
## Class to wrapper control of the Playing With Fusion IR pi Hat
######################################################################
class SnakeEyesBoardControl():
    LED_PWM_DIM_PIN = 13 

    def __init__(self):
        self.pwmNormCMD = 0
        GPIO.setmode(GPIO.BCM)
        GPIO.setup(self.LED_PWM_DIM_PIN, GPIO.OUT)
        self.ledCtrl = GPIO.PWM(self.LED_PWM_DIM_PIN,800)
        self.ledCtrl.start(0)

    def _update(self):
        if(self.pwmNormCMD > 1.0):
            self.pwmNormCMD = 1.0
        elif(self.pwmNormCMD < 0.0):
            self.pwmNormCMD = 0.0
        self.ledCtrl.ChangeDutyCycle(self.pwmNormCMD*100.0)

    """ Public API to set the brightness of the LED Array. 
        0.0 is off, 1.0 is full brightness.
    """
    def setBrightness(self, val):
        self.pwmNormCMD = val
        self._update()

    def shutdown(self):
        self.pwmNormCMD = 0
        self._update()
        self.ledCtrl.stop()
        GPIO.cleanup()




######################################################################
## NOIR-Specific configuration for FRC Vision Processing applications
## Tweak as needed, but hopefully this set is a good start.
######################################################################
def configureNOIRCam():
        print("Configuring NOir Camera...")
        cmdStart="v4l2-ctl --set-ctrl "
        #Turns off Auto setting that would change the ones we put in place
        os.system(cmdStart+"auto_exposure=1")
        os.system(cmdStart+"white_balance_auto_preset=0")

        #User Controls
        os.system(cmdStart+"brightness=30")
        os.system(cmdStart+"contrast=100")
        os.system(cmdStart+"saturation=10")
        os.system(cmdStart+"red_balance=1000")
        os.system(cmdStart+"blue_balance=1000")
        os.system(cmdStart+"horizontal_flip=0")
        os.system(cmdStart+"vertical_flip=0")
        os.system(cmdStart+"power_line_frequency=2")
        os.system(cmdStart+"sharpness=100")
        os.system(cmdStart+"color_effects=0")
        os.system(cmdStart+"rotate=0")
        os.system(cmdStart+"color_effects_cbcr=3896")

        #Codec Controls
        os.system(cmdStart+"video_bitrate_mode=1")
        os.system(cmdStart+"video_bitrate=25000000")
        os.system(cmdStart+"repeat_sequence_header=0")
        os.system(cmdStart+"h264_i_frame_period=60")
        os.system(cmdStart+"h264_level=11")
        os.system(cmdStart+"h264_profile=4")

        #Camera Controls
        os.system(cmdStart+"exposure_time_absolute=93")
        os.system(cmdStart+"exposure_dynamic_framerate=0")
        os.system(cmdStart+"auto_exposure_bias=0")
        os.system(cmdStart+"image_stabilization=0")
        os.system(cmdStart+"iso_sensitivity=0")
        os.system(cmdStart+"iso_sensitivity_auto=0")
        os.system(cmdStart+"exposure_metering_mode=0")
        os.system(cmdStart+"scene_mode=0")

        #JPEG Compression controls
        os.system(cmdStart+"compression_quality=100")



######################################################################
## Simple web-server implementation to stream MJPEG video for
## debug purposes.
######################################################################
class CamHandler(BaseHTTPRequestHandler):
    def do_GET(self):
        global img
        if self.path == '/cam.mjpg':
            # Handle requests to see the mjpg stream by sending images as they are available.
            self.send_response(200)
            self.send_header('Age', 0)
            self.send_header('Cache-Control', 'no-cache, private')
            self.send_header('Pragma', 'no-cache')
            self.send_header('Connection', 'close')
            self.send_header('Content-Type', 'multipart/x-mixed-replace; boundary=FRAME')
            self.end_headers()
            time.sleep(0.1)
            while True:
                try:
                    if img is not None:
                        _, jpg = cv2.imencode('.jpg', img)
                        self.wfile.write(b'--FRAME\r\n')
                        self.send_header('Content-type', 'image/jpeg')
                        self.send_header('Content-length', str(jpg.size))
                        self.end_headers()
                        sendData = jpg.tostring()
                        self.wfile.write(sendData)
                        self.wfile.write(b'\r\n\r\n')
                        
                        
                except KeyboardInterrupt:
                    print("Keyboard Interrupt Detected")
                    break
                except ConnectionResetError:
                    print("Client Disconnect - Connection Reset")
                    break
                except BrokenPipeError:
                    print("Client Disconnected - Broken Pipe")
                    break

        else:
            
            if self.path == '/':
                self.send_response(301)
                self.send_header('Location', '/stream.html')
                self.end_headers()

            else:

                if self.path == '/stream.html':
                    # Handle requests to see a more friendly stream page with the image on it.
                    webHTMLContent = """<html>
                                        <head></head>
                                        <body>
                                            <img src="cam.mjpg" height="90%"/>
                                        </body>
                                        </html>"""
                    self.send_response(200)
                    self.send_header('Content-type','text/html')
                    self.send_header('Content-Length', len(webHTMLContent))
                    self.end_headers()

                else:
                    # Throw 404 at everything else.
                    webHTMLContent = """<html>
                                        <head></head>
                                        <body>
                                            <p> <h1> 404 <br> This page does not exist. <br> Sad panda. </h1> </p>
                                        </body>
                                        </html>"""
                    self.send_response(404)
                    self.send_header('Content-type','text/html')
                    self.send_header('Content-Length', len(webHTMLContent))
                    self.end_headers()

                
                if webServerPrintDebug:
                    print("Serving {} to {}".format(self.path, self.client_address))
                    print(webHTMLContent)

                self.wfile.write(webHTMLContent.encode("utf-8"))
            

class ThreadedHTTPServer(ThreadingMixIn, HTTPServer):
    """Handle requests in a separate thread."""
    allow_reuse_address = True
    daemon_threads = True

######################################################################
## Class for tracking performacne of the vision pipeline
######################################################################
class PerformanceTracker():
    def __init__(self):
        self.prevStartTimeSec = 0
        self.curStartTimeSec = 0
        self.curImgRxTimeSec = 0
        self.curEndTimeSec = 0
        self.curFPS = 0
        self.curPipelineDelaySec = 0

        self.NUM_FRAMES_FPS_AVG = 20
        self.fps_avg_buf = collections.deque(maxlen=self.NUM_FRAMES_FPS_AVG)

    def now(self):
        return time.time_ns() / (10 ** 9) # convert to floating-point seconds

    def getCurFPS(self):
        return 1/(self.curStartTimeSec - self.prevStartTimeSec)

    def markLoopStart(self):
        self.prevStartTimeSec = self.curStartTimeSec
        self.curStartTimeSec = self.now()
        self.fps_avg_buf.append(self.getCurFPS())

    def markImgReadDone(self):
        self.curImgRxTimeSec = self.now()

    def markLoopEnd(self):
        self.curEndTimeSec = self.now()

    def getCurFPSAvg(self):
        return sum(self.fps_avg_buf)/float(self.NUM_FRAMES_FPS_AVG)

    def getPlDelay(self):
        return self.curEndTimeSec - self.curImgRxTimeSec



######################################################################
## Main Code Execution Starts Here
######################################################################
if __name__ == "__main__":
    
    #Cross-thread lastest-image sharing
    global img
    img = None
    

    print("PWF Sample NOIR Processing starting")
    print("Python Version {}".format(str(sys.version)))
    print("OpenCV Version: {}".format(cv2.__version__))
    print("numpy Version: {}".format(np.__version__))


    # Set up the NOIR camera to desired settings
    configureNOIRCam()

    # Start NetworkTables
    ntinst = NetworkTablesInstance.getDefault()
    print("Setting up NetworkTables client for team {}".format(TEAM_NUMBER))
    ntinst.startClientTeam(TEAM_NUMBER)
    ntTable = NetworkTables.getTable("VisionData")

    # Start the Video Capture from the camera
    capture = cv2.VideoCapture(0)
    capture.set(cv2.CAP_PROP_FRAME_WIDTH, CAPTURE_WIDTH)
    capture.set(cv2.CAP_PROP_FRAME_HEIGHT, CAPTURE_HEIGHT)
    capture.set(cv2.CAP_PROP_FPS, CAPTURE_FPS)

    # Start up the results-view web server
    try:
        server = ThreadedHTTPServer(('wpilibpi.local', 5805), CamHandler)
        t = threading.Thread(target=server.serve_forever)
        t.start()
    except KeyboardInterrupt:
        capture.release()
        server.socket.close()


    leds = SnakeEyesBoardControl()
    leds.setBrightness(LED_BRIGHTNESS) 
    import atexit
    atexit.register(leds.shutdown) #Todo, this is very inelegant but maybe it'll work?

    # Init object to process the camera images
    pl = SimpleVisionPipeline()

    # Init object to track overall pipeline timing performance
    pt = PerformanceTracker()
    

    # Run periodically forever
    print("Vision Processing Starting..")
    while True:     
        pt.markLoopStart()

        # Read next frame from the camera
        rc,cam_img = capture.read() 
        pt.markImgReadDone()

        if not rc:
            img = None
            print("Bad Image Capture!")
            continue
        else:
            img = pl.process(cam_img) # If the captured image was good, run it through the processing

        pl.setDispFPS(pt.getCurFPSAvg())

        time.sleep(0) # Yield to other threads (webserver & streaming)
        pt.markLoopEnd()

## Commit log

2020-12-16 Fixed main board picture file extension
2021-03-07 moar broken links and typos!
    [snakeEyesVision.py]
2021-12-29 2022 Doc Updates (#4)
    * PhotonVision Pi Image Gen
    * Streamlined case/hardware docs
    [Parts - Bottom.stl, Parts - Camera Board Spacer Plate.stl, Parts - Main Board Spacer.stl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]
2022-09-18 updated case top and bottom for better fit around fan
    [Parts - Bottom.stl, Parts - Top.stl]
2023-01-18 revised case and latest photonvision
    [Case Bottom.stl, Case Top.stl, Parts - Bottom.stl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]
2023-01-18 Update and rename sampleCase.md to readme.md
2023-12-27 Switched to SQL configuration
